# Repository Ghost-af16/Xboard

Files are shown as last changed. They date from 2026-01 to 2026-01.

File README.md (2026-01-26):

Its an RP2040 devboard which i make using the Guide which i can use in my projects 

**PCB**









**JLCPCB**





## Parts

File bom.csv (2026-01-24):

Designator | Footprint | Quantity | Value | LCSC Part #
C1, C10, C18 | 0402 | 3 | 1uF
C11, C12, C17, C2, C21, C3, C4, C5, C6, C7, C8, C9 | 0402 | 12 | 0.1uF
C13, C14 | 0402 | 2 | 10uF
C15, C16 | 0402 | 2 | 33pF
C19, C20 | 0402 | 2 | 4.7uF
D1, D2 | 0402 | 2 | LED
J1 | USB_C_Receptacle_HRO_TYPE-C-31-M-12 | 1 | USB_C_Receptacle_USB2.0_14P
J2, J3 | PinHeader_1x20_P2.54mm_Vertical | 2 | Conn_01x20
J4 | PinHeader_1x02_P2.54mm_Vertical | 1 | Conn_01x02
J5 | PinHeader_1x04_P2.54mm_Vertical | 1 | Conn_01x04
R1, R2 | 0402 | 2 | 5.1k
R10 | 0402 | 1 | 4.12K
R11 | 0402 | 1 | 1.18K
R12 | 0402 | 1 | 1.13K
R13, R14, R6 | 0402 | 3 | 10K
R3, R4 | 0402 | 2 | 27Ω
R5, R7 | 0402 | 2 | 1K
R8, R9 | 0402 | 2 | 1.5K
SW1, SW3 | SW_Push_SPST_NO_Alps_SKRK | 2 | SW_Push
U1 | QFN-56-1EP_7x7mm_P0.4mm_EP3.2x3.2mm | 1 | RP2040
U2 | SOT-23 | 1 | MCP1700x-330xxTT
U3 | VQFN-16-1EP_3x3mm_P0.5mm_EP1.6x1.6mm | 1 | BQ24074RGT
U4 | Winbond_USON-8-1EP_3x2mm_P0.5mm_EP0.2x1.6mm | 1 | W25Q16JVUXIQ TR
Y1 | Crystal_SMD_3225-4Pin_3.2x2.5mm | 1 | 12 MHz

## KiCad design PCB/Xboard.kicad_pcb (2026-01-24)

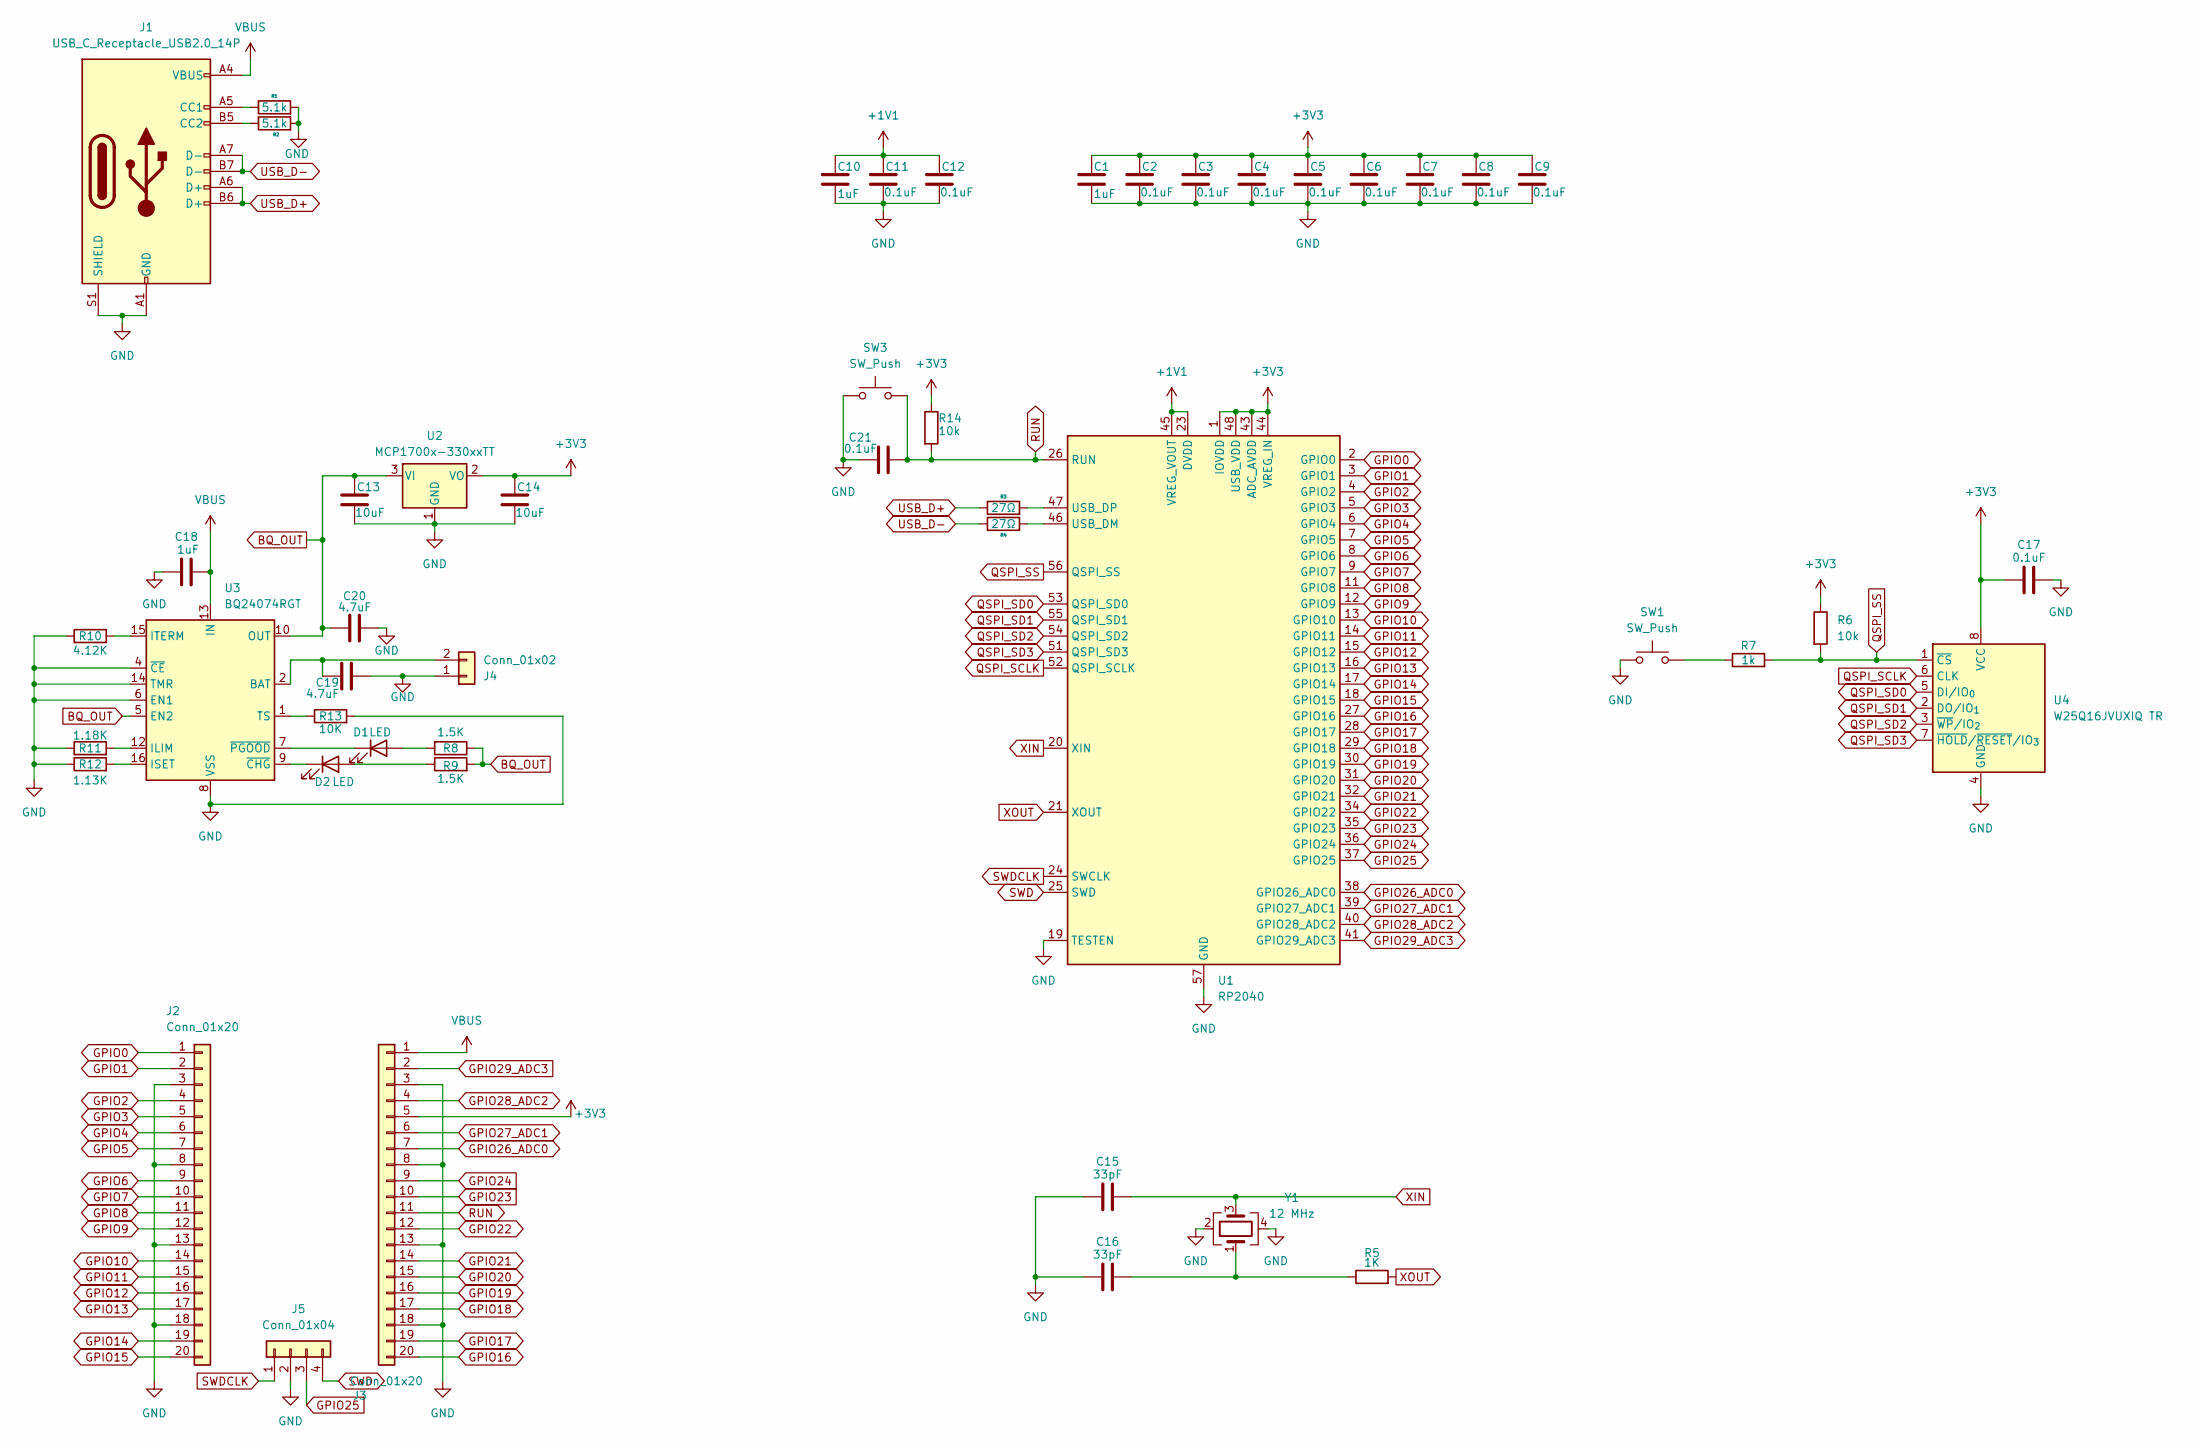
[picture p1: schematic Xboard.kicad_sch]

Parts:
C1, C10, C18: 1uF; C_0402_1005Metric
C2, C3, C4, C5, C6, C7, C8, C9, C11, C12, C17, C21: 0.1uF; C_0402_1005Metric
C13, C14: 10uF; C_0402_1005Metric
C15, C16: 33pF; C_0402_1005Metric
C19, C20: 4.7uF; C_0402_1005Metric
D1, D2: LED; LED_0402_1005Metric
J1: USB_C_Receptacle_USB2.0_14P; USB_C_Receptacle_HRO_TYPE-C-31-M-12
J2, J3: Conn_01x20; PinHeader_1x20_P2.54mm_Vertical
J4: Conn_01x02; PinHeader_1x02_P2.54mm_Vertical
J5: Conn_01x04; PinHeader_1x04_P2.54mm_Vertical
R1, R2: 5.1k; R_0402_1005Metric
R3, R4: 27Ω; R_0402_1005Metric
R5: 1K; R_0402_1005Metric
R6, R14: 10k; R_0402_1005Metric
R7: 1k; R_0402_1005Metric
R8, R9: 1.5K; R_0402_1005Metric
R10: 4.12K; R_0402_1005Metric
R11: 1.18K; R_0402_1005Metric
R12: 1.13K; R_0402_1005Metric
R13: 10K; R_0402_1005Metric
SW1, SW3: SW_Push; SW_Push_SPST_NO_Alps_SKRK
U1: RP2040; QFN-56-1EP_7x7mm_P0.4mm_EP3.2x3.2mm
U2: MCP1700x-330xxTT; SOT-23
U3: BQ24074RGT; VQFN-16-1EP_3x3mm_P0.5mm_EP1.6x1.6mm
U4: W25Q16JVUXIQ TR; Winbond_USON-8-1EP_3x2mm_P0.5mm_EP0.2x1.6mm
Y1: 12 MHz; Crystal_SMD_3225-4Pin_3.2x2.5mm

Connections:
+1V1: C10.1, C11.1, C12.1, U1.23 (DVDD), U1.45 (VREG_VOUT), U1.50 (DVDD)
+3V3: C1.1, C2.1, C3.1, C4.1, C5.1, C6.1, C7.1, C8.1, C9.1, C14.1, C17.1, J3.5, R6.1, R14.1, U1.1 (IOVDD), U1.10 (IOVDD), U1.22 (IOVDD), U1.33 (IOVDD), U1.42 (IOVDD), U1.43 (ADC_AVDD), U1.44 (VREG_IN), U1.48 (USB_VDD), U1.49 (IOVDD), U2.2 (VO), U4.8 (VCC)
BQ_OUT: C13.1, C20.1, R8.1, R9.2, U2.3 (VI), U3.5 (EN2), U3.10 (OUT), U3.11 (OUT)
GND: C1.2, C2.2, C3.2, C4.2, C5.2, C6.2, C7.2, C8.2, C9.2, C10.2, C11.2, C12.2, C13.2, C14.2, C15.1, C16.1, C17.2, C18.1, C19.2, C20.2, C21.2, J1.A1 (GND), J1.A12 (GND), J1.B1 (GND), J1.B12 (GND), J1.S1 (SHIELD), J2.3, J2.8, J2.13, J2.18, J3.3, J3.8, J3.13, J3.18, J4.1, J5.2, R1.2, R2.2, R10.1, R11.1, R12.1, R13.2, SW1.1, SW3.1, U1.19 (TESTEN), U1.57 (GND), U2.1 (GND), U3.4 (~CE), U3.6 (EN1), U3.8 (VSS), U3.14 (TMR), U3.17 (VSS), U4.4 (GND), Y1.2, Y1.4
GPIO0: J2.1, U1.2 (GPIO0)
GPIO1: J2.2, U1.3 (GPIO1)
GPIO2: J2.4, U1.4 (GPIO2)
GPIO3: J2.5, U1.5 (GPIO3)
GPIO4: J2.6, U1.6 (GPIO4)
GPIO5: J2.7, U1.7 (GPIO5)
GPIO6: J2.9, U1.8 (GPIO6)
GPIO7: J2.10, U1.9 (GPIO7)
GPIO8: J2.11, U1.11 (GPIO8)
GPIO9: J2.12, U1.12 (GPIO9)
GPIO10: J2.14, U1.13 (GPIO10)
GPIO11: J2.15, U1.14 (GPIO11)
GPIO12: J2.16, U1.15 (GPIO12)
GPIO13: J2.17, U1.16 (GPIO13)
GPIO14: J2.19, U1.17 (GPIO14)
GPIO15: J2.20, U1.18 (GPIO15)
GPIO16: J3.20, U1.27 (GPIO16)
GPIO17: J3.19, U1.28 (GPIO17)
GPIO18: J3.17, U1.29 (GPIO18)
GPIO19: J3.16, U1.30 (GPIO19)
GPIO20: J3.15, U1.31 (GPIO20)
GPIO21: J3.14, U1.32 (GPIO21)
GPIO22: J3.12, U1.34 (GPIO22)
GPIO23: J3.10, U1.35 (GPIO23)
GPIO24: J3.9, U1.36 (GPIO24)
GPIO25: J5.3, U1.37 (GPIO25)
GPIO26_ADC0: J3.7, U1.38 (GPIO26_ADC0)
GPIO27_ADC1: J3.6, U1.39 (GPIO27_ADC1)
GPIO28_ADC2: J3.4, U1.40 (GPIO28_ADC2)
GPIO29_ADC3: J3.2, U1.41 (GPIO29_ADC3)
unnamed: C16.2, R5.1, Y1.1
unnamed: D1.2 (A), R8.2
unnamed: D1.1 (K), U3.7 (~PGOOD)
unnamed: D2.2 (A), R9.1
unnamed: D2.1 (K), U3.9 (~CHG)
unnamed: J1.A5 (CC1), R1.1
unnamed: J1.B5 (CC2), R2.1
unnamed: C19.1, J4.2, U3.2 (BAT), U3.3 (BAT)
unnamed: R7.1, SW1.2
unnamed: R4.2, U1.46 (USB_DM)
unnamed: R3.2, U1.47 (USB_DP)
unnamed: R11.2, U3.12 (ILIM)
unnamed: R12.2, U3.16 (ISET)
unnamed: R10.2, U3.15 (ITERM)
unnamed: R13.1, U3.1 (TS)
QSPI_SCLK: U1.52 (QSPI_SCLK), U4.6 (CLK)
QSPI_SD0: U1.53 (QSPI_SD0), U4.5 (DI/IO_{0})
QSPI_SD1: U1.55 (QSPI_SD1), U4.2 (DO/IO_{1})
QSPI_SD2: U1.54 (QSPI_SD2), U4.3 (~WP/IO_{2})
QSPI_SD3: U1.51 (QSPI_SD3), U4.7 (~HOLD/~RESET/IO_{3})
QSPI_SS: R6.2, R7.2, U1.56 (QSPI_SS), U4.1 (~CS)
RUN: C21.1, J3.11, R14.2, SW3.2, U1.26 (RUN)
SWD: J5.4, U1.25 (SWD)
SWDCLK: J5.1, U1.24 (SWCLK)
USB_D+: J1.A6 (D+), J1.B6 (D+), R3.1
USB_D-: J1.A7 (D-), J1.B7 (D-), R4.1
VBUS: C18.2, J1.A4 (VBUS), J1.A9 (VBUS), J1.B4 (VBUS), J1.B9 (VBUS), J3.1, U3.13 (IN)
XIN: C15.2, U1.20 (XIN), Y1.3
XOUT: R5.2, U1.21 (XOUT)

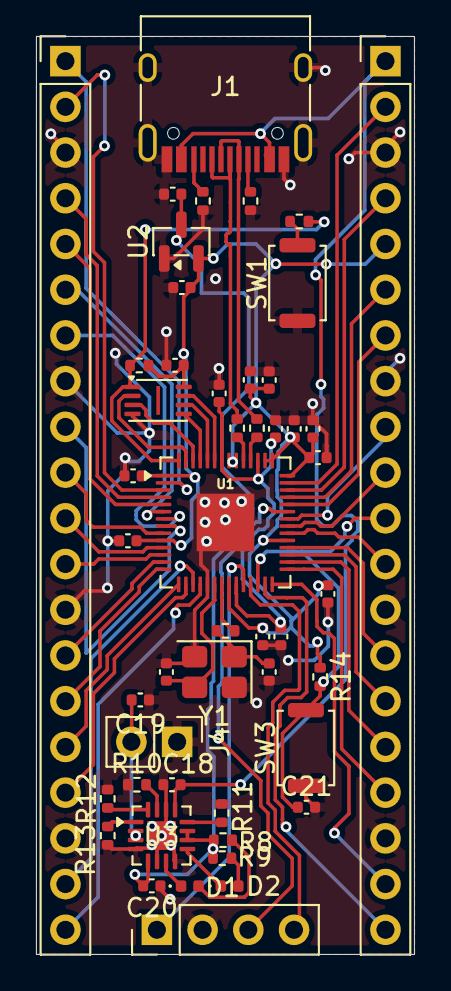
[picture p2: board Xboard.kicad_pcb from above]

Board: 2 copper layers, 21.0 x 51.0 mm, 49 parts (0 on the bottom side), 63 nets.
